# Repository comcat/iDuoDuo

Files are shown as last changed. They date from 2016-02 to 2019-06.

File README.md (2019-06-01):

iDuoDuo - Pet APRS Tracker
=======================================

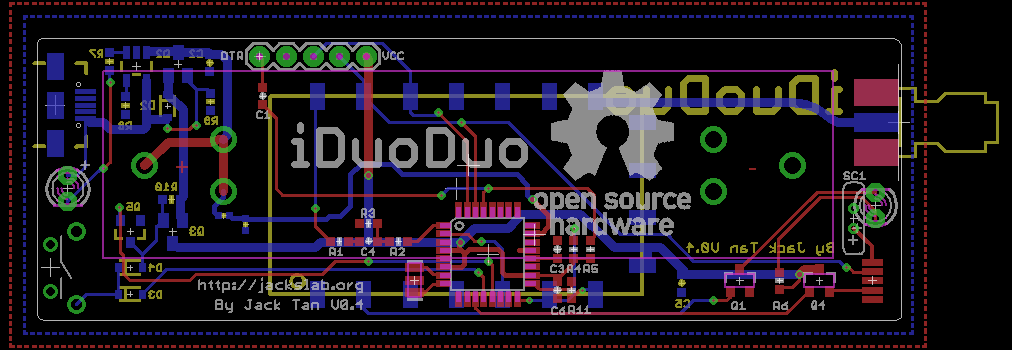
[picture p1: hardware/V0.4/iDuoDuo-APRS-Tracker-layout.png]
iDuoDuo Board V0.4


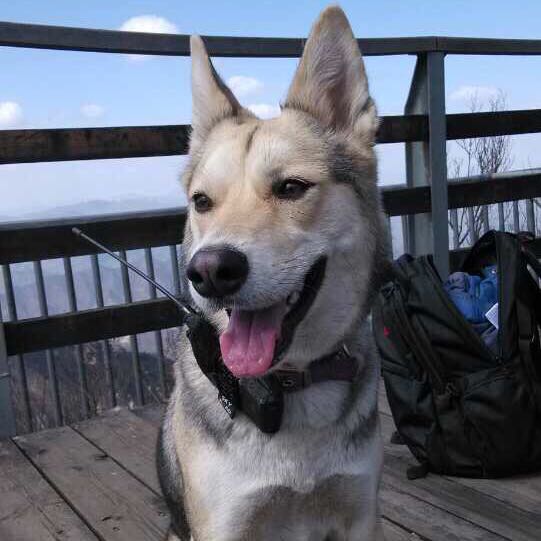
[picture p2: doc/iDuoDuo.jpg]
My DuoDuo


More photo of My DuoDuo :) [My DuoDuo Life](http://comcat.lofter.com/tag/%E5%A4%9A%E5%A4%9A)

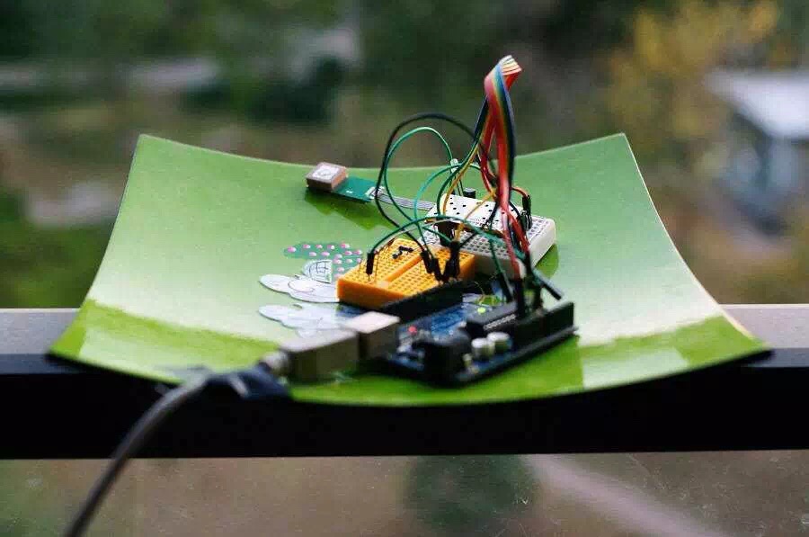
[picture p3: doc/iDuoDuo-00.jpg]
iDuoDuo prototype


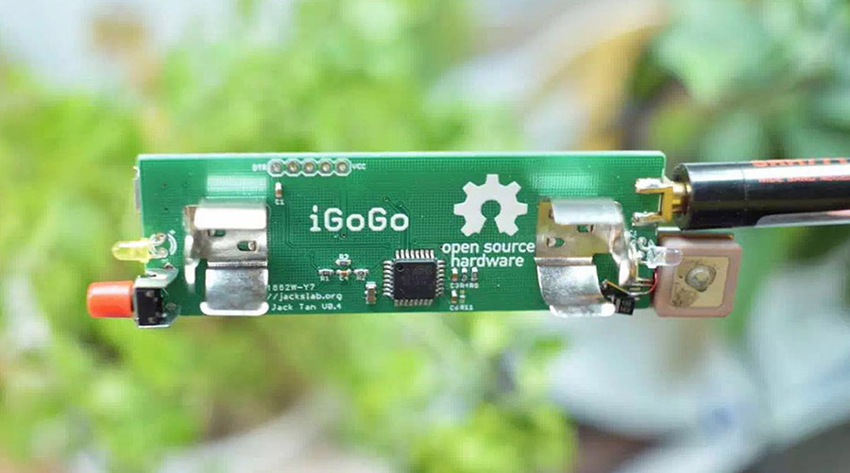
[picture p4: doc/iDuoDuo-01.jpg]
iDuoDuo V0.4


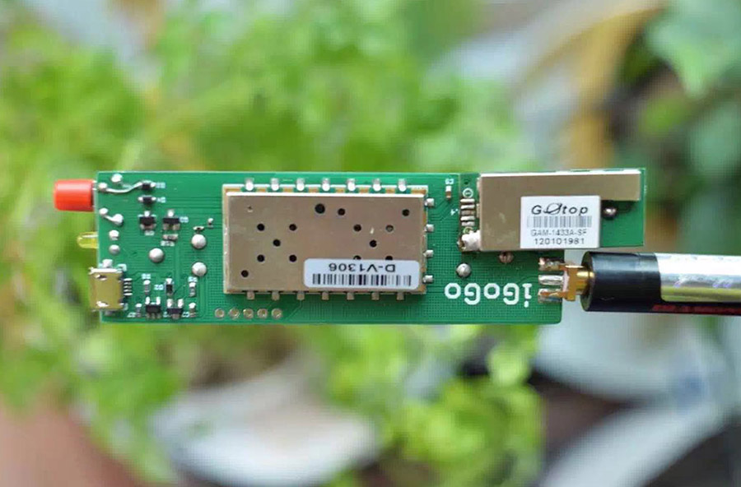
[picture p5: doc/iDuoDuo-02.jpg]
iDuoDuo V0.4


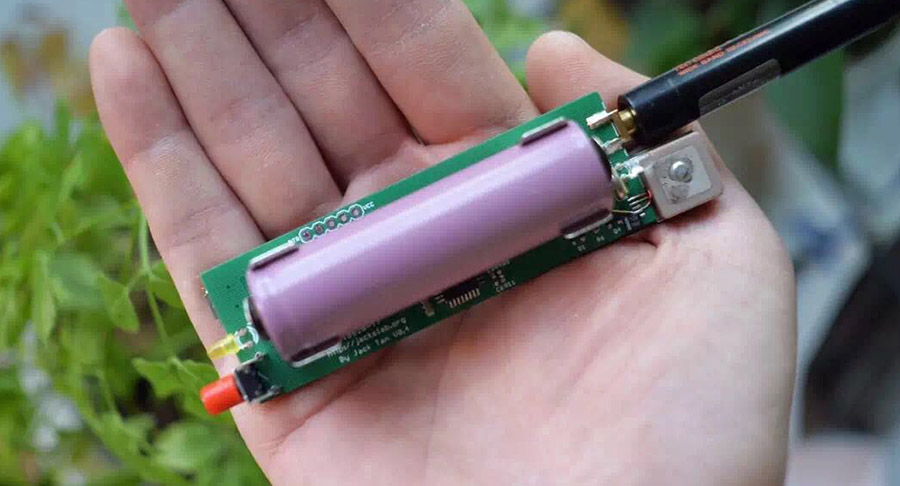
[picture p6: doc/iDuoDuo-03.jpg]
iDuoDuo V0.4


[*iDuoDuo Board*](http://jackslab.org/)

Features
-------------------
* ATMEGA328p MCU, Arduino compatible
* 1W VHF radio module, low cost, about $5 ([SR_FRS_1WV](https://item.taobao.com/item.htm?id=21278567784))
* 1200 bauds AFSK using 8-bit PWM
* Sends out standard APRS position messages
* mini GPS module
* 18650 power supply
* Open Source hardware and firmware 

Pin map
-------------------
iDuoDuo board

* D3 is the audio out pin
* D4 is the PTT pin
* D12 is the PD pin of radio module
* D13 is the PWR_CTRL pin of the radio module

* D8 is the power on input pin
* D9 is the power on output pin

Repository Contents
-------------------
* hardware/ - All Eagle design files (.brd, .sch) and Gerber files of iDuoDuo Board 
* firmware/ - Firmware source files of the iDuoDuo

Product Versions
----------------
* [IDuoDuo-V0.4](hardware/V0.4/) - Stupid bug of the S1 key package. 2016/02/09
* [IDuoDuo-V0.6](hardware/V0.6/) - work OK.

License Information
-------------------
The hardware is released under [Creative Commons ShareAlike 4.0 International](https://creativecommons.org/licenses/by-sa/4.0/).

Distributed as-is; no warranty is given.

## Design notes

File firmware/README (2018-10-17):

How to compile the firmware:
---------------------------------

1. Launch the Arduino IDE(arduino-0022) and open up the firmware.pde

2. Locate the "config.h" tab and replace settings with your own (YOUR CALLSIGN
   GOES THERE).

3. When uploading the firmware, unplug the GPS or flashing will fail with an
error.

http://github.com/trackuino

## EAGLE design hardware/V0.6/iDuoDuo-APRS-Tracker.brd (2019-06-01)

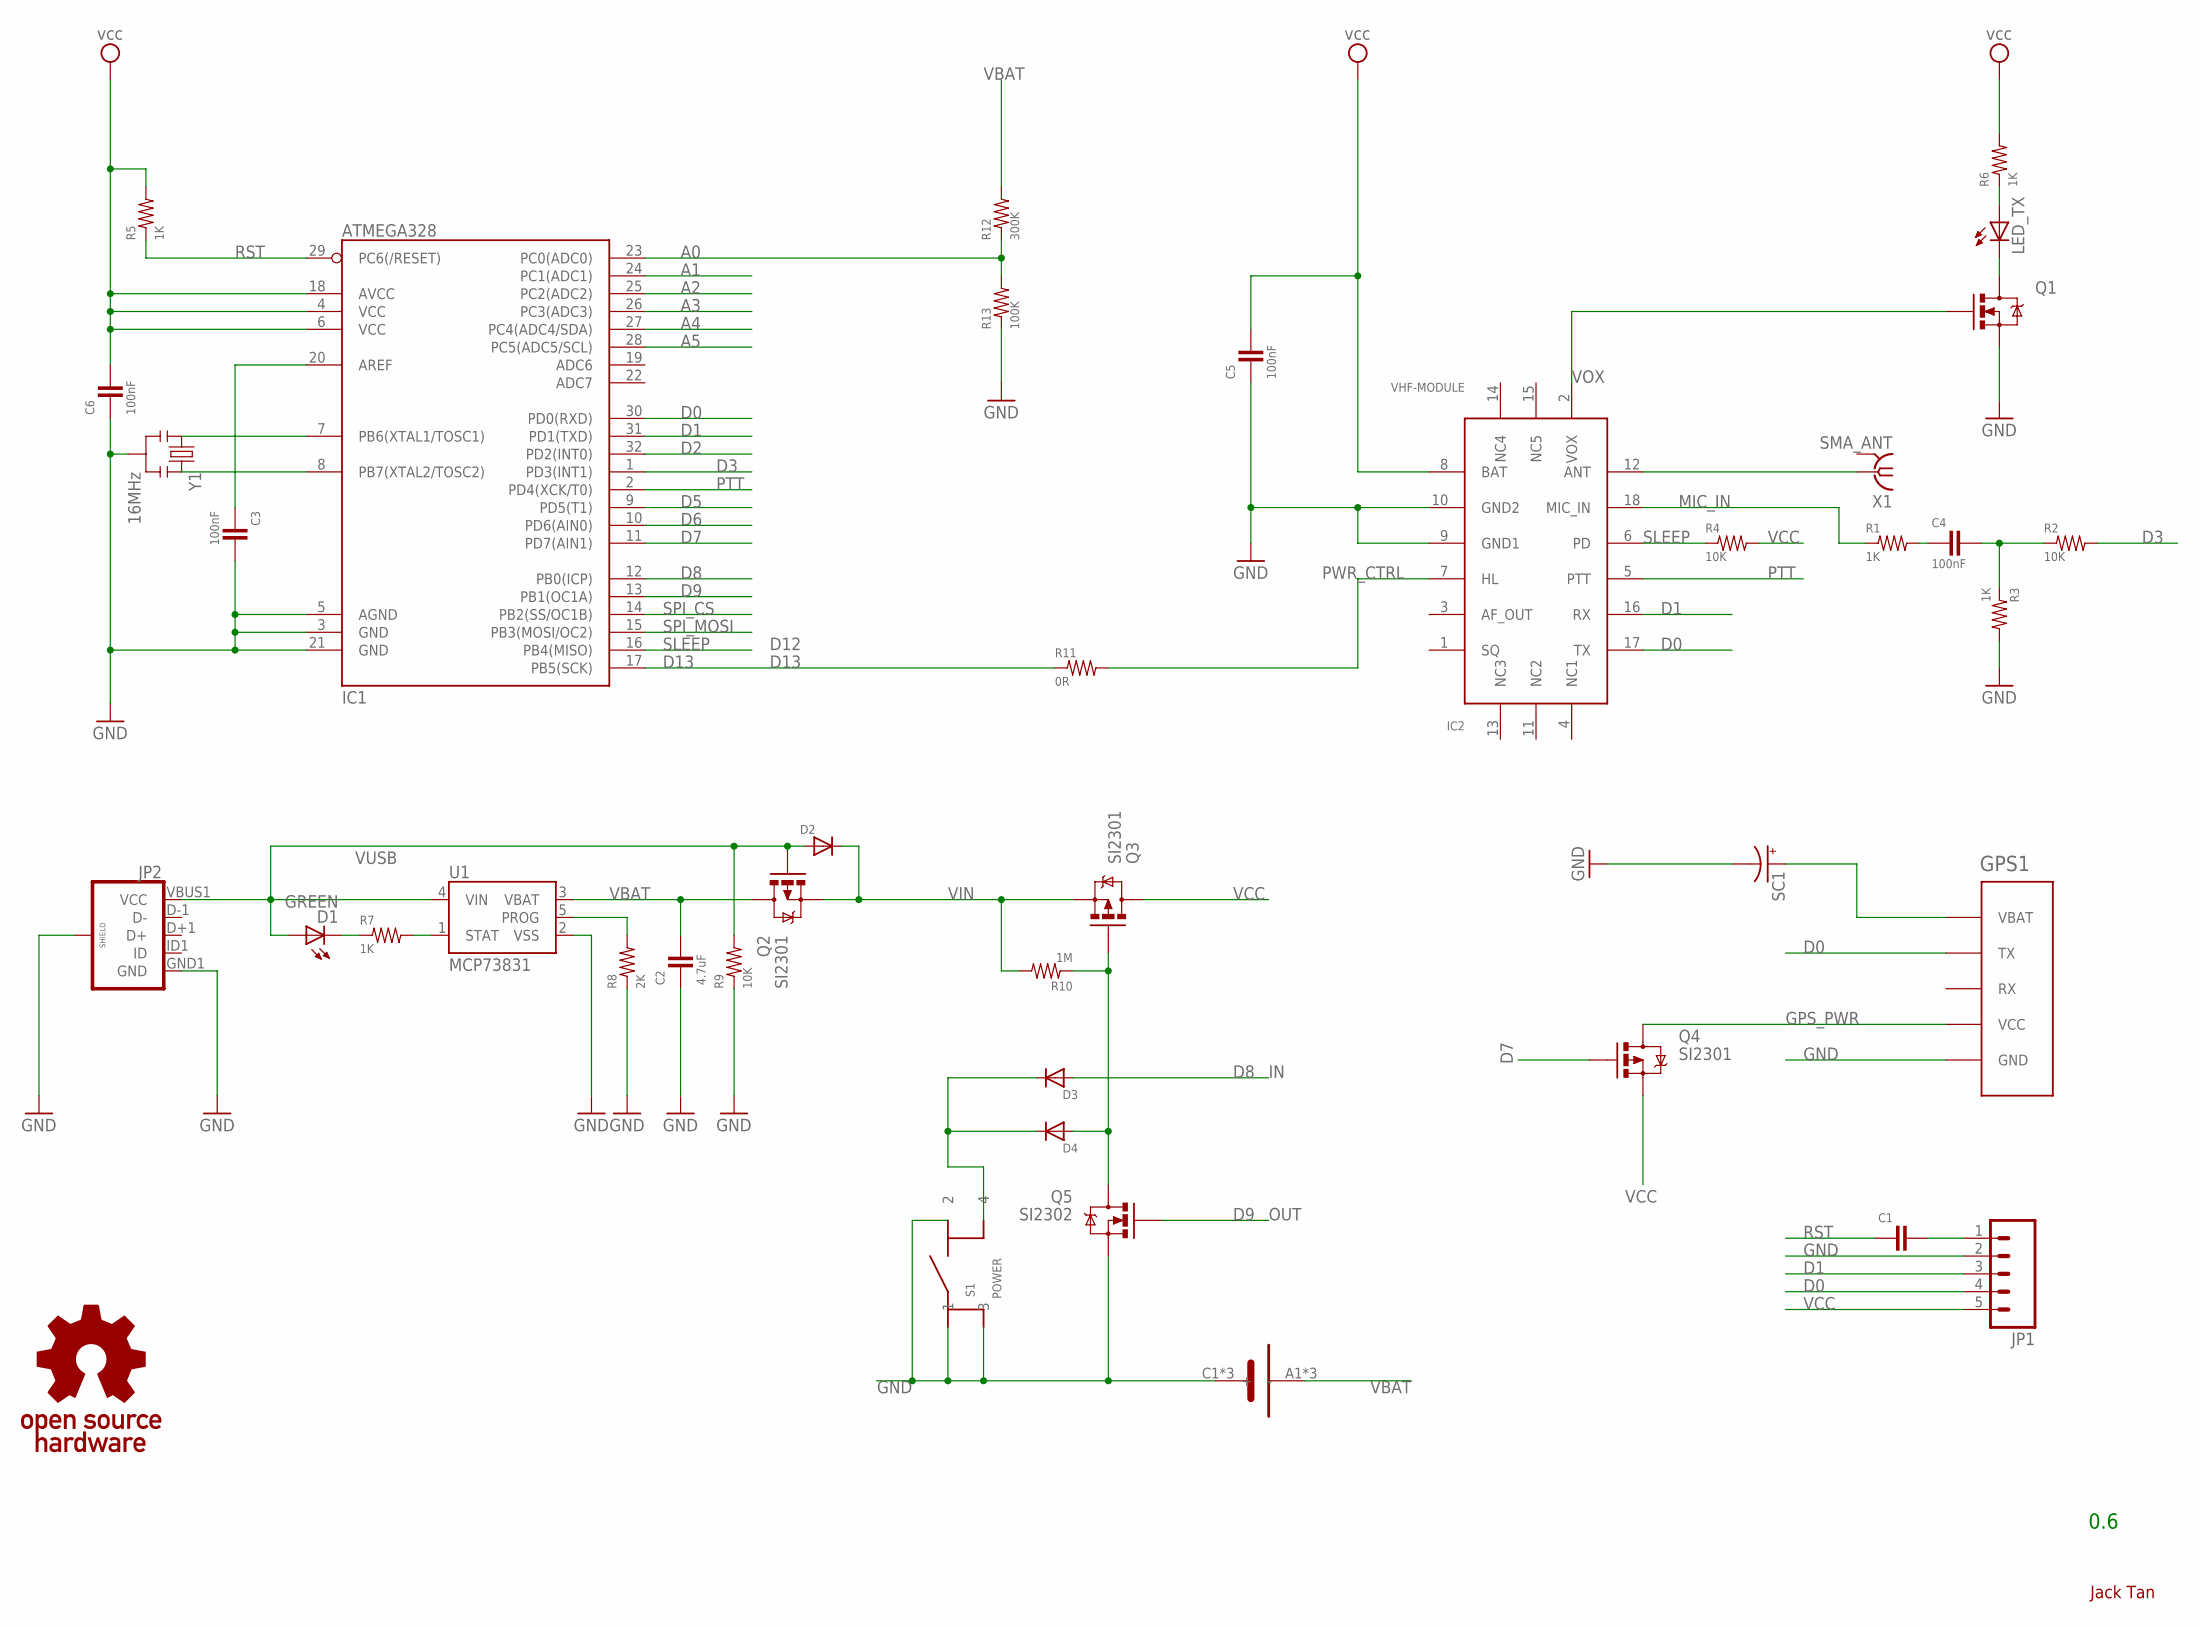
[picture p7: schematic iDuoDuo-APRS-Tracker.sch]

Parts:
B1: 18650
C1: 0603-CAP
C2: 4.7uF; 0603-CAP
C3, C4, C5, C6: 100nF; 0603-CAP
D1: GREEN; LED3MM
D2, D3, D4: DIODESOD; SOD-323
GPS1: GAM-1433
IC1: ATMEGA328; TQFP32-08
IC2: VHF-MODULE
JP1: M05PTH; 1X05
JP2: USB_MICROB_PLUGCONN-11752; USB-B-MICRO-SMD_V03
LED_TX: LED3MM
Q1: MOSFET-N-SMD; SOT23-3
Q2, Q3, Q4: SI2301; SOT23
Q5: SI2302; SOT23-3
R1, R3, R5, R6, R7: 1K; 0603-RES
R2, R4, R9: 10K; 0603-RES
R8: 2K; 0603-RES
R10: 1M; 0603-RES
R11: 0R; 0603-RES
R12: 300K; 0402-RES
R13: 100K; 0402-RES
S1: POWER; SWITCH-TS-038
SC1: SC-3.3-0.22F
U1: MCP73831; SOT23-5
U$1: OPEN_HARDWARE_LOGO
X1: SMA_ANT; SMA-KE
Y1: 16MHz; RESONATOR-SMD

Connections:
A0: IC1.23 (PC0(ADC0)), R12.1, R13.2
A1: IC1.24 (PC1(ADC1))
A2: IC1.25 (PC2(ADC2))
A3: IC1.26 (PC3(ADC3))
A4: IC1.27 (PC4(ADC4/SDA))
A5: IC1.28 (PC5(ADC5/SCL))
D0: GPS1.P$2 (TX), IC1.30 (PD0(RXD)), IC2.17 (TX), JP1.4
D1: IC1.31 (PD1(TXD)), IC2.16 (RX), JP1.3
D2: IC1.32 (PD2(INT0))
D3: IC1.1 (PD3(INT1)), R2.2
D5: IC1.9 (PD5(T1))
D6: IC1.10 (PD6(AIN0))
D7: IC1.11 (PD7(AIN1)), Q4.1 (G)
D8: D3.2 (A), IC1.12 (PB0(ICP))
D9: IC1.13 (PB1(OC1A)), Q5.1 (G)
D13: IC1.17 (PB5(SCK)), R11.1
GND: B1.C1 (-), B1.C2 (-), B1.C3 (-), C2.1, C3.2, C5.1, C6.1, GPS1.P$5 (GND), IC1.3 (GND), IC1.5 (AGND), IC1.21 (GND), IC2.9 (GND1), IC2.10 (GND2), JP1.2, JP2.GND1 (GND), JP2.SHIELD1 (SHIELD), JP2.SHIELD2 (SHIELD), JP2.SHIELD3 (SHIELD), Q1.2 (S), Q5.2 (S), R3.2, R8.1, R9.1, R13.1, S1.1, S1.2, S1.3, SC1.2 (-), U1.2 (VSS), X1.G@1 (GND), X1.G@2 (GND), X1.G@3 (GND), X1.G@4 (GND), Y1.2
GPS_PWR: GPS1.P$4 (VCC), Q4.3 (D)
MIC_IN: IC2.18 (MIC_IN), R1.1
unnamed: IC1.7 (PB6(XTAL1/TOSC1)), Y1.1
unnamed: IC1.8 (PB7(XTAL2/TOSC2)), Y1.3
unnamed: IC2.12 (ANT), X1.1
unnamed: C4.1, R1.2
unnamed: C4.2, R2.1, R3.1
unnamed: C3.1, IC1.20 (AREF)
unnamed: D4.2 (A), Q3.1 (G), Q5.3 (D), R10.1
unnamed: LED_TX.K (C), Q1.3 (D)
unnamed: LED_TX.A, R6.1
unnamed: GPS1.P$1 (VBAT), SC1.1 (+)
unnamed: C1.2, JP1.1
unnamed: D1.K (C), R7.1
unnamed: R7.2, U1.1 (STAT)
unnamed: R8.2, U1.5 (PROG)
unnamed: D3.1 (C), D4.1 (C), S1.4
PTT: IC1.2 (PD4(XCK/T0)), IC2.5 (PTT)
PWR_CTRL: IC2.7 (HL), R11.2
RST: C1.1, IC1.29 (PC6(/RESET)), R5.1
SLEEP: IC1.16 (PB4(MISO)), IC2.6 (PD), R4.1
SPI_CS: IC1.14 (PB2(SS/OC1B))
SPI_MOSI: IC1.15 (PB3(MOSI/OC2))
VBAT: B1.A1 (+), B1.A2 (+), B1.A3 (+), C2.2, Q2.3 (D), R12.2, U1.3 (VBAT)
VCC: C5.2, C6.2, IC1.4 (VCC), IC1.6 (VCC), IC1.18 (AVCC), IC2.8 (BAT), JP1.5, Q3.3 (D), Q4.2 (S), R4.2, R5.2, R6.2
VIN: D2.1 (C), Q2.2 (S), Q3.2 (S), R10.2
VOX: IC2.2 (VOX), Q1.1 (G)
VUSB: D1.A, D2.2 (A), JP2.VBUS1 (VCC), Q2.1 (G), R9.2, U1.4 (VIN)

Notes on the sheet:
0.6
Jack Tan
OUT
D12
D13

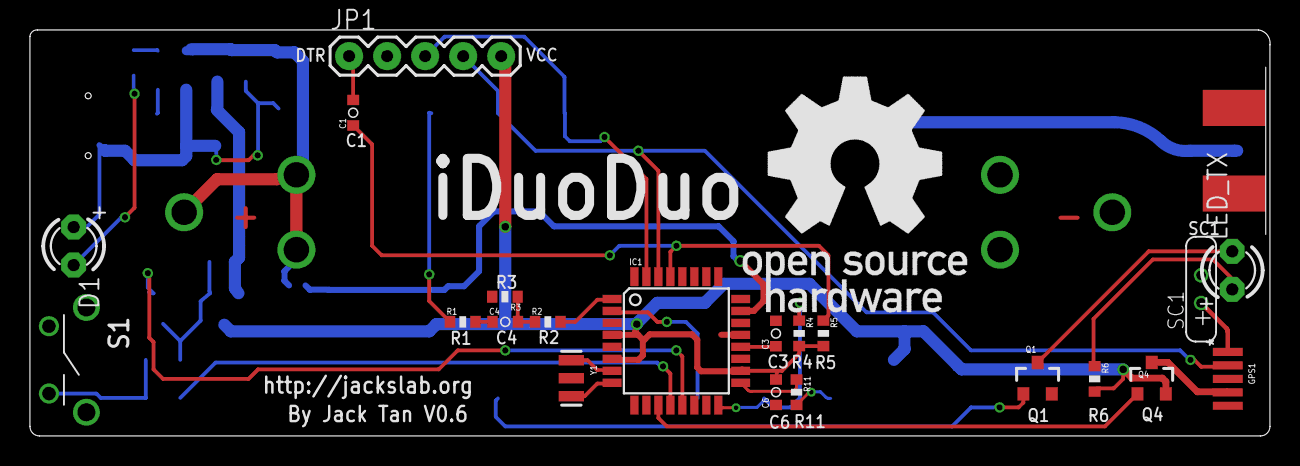
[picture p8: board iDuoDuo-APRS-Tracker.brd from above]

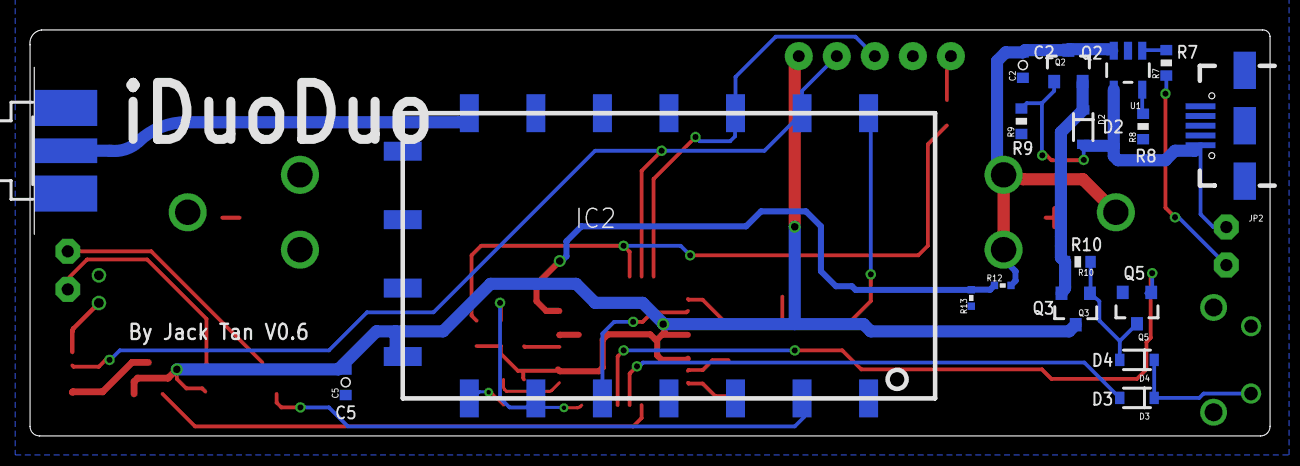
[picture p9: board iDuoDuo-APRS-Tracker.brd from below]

Board: 2 copper layers, 82.8 x 27.1 mm, 41 parts (18 on the bottom side), 35 nets.

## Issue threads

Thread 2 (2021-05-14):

Bill of Materials

DanielSchetritt, 2021-05-14:
Hello!

This is a great project! I want to build one myself. Where can I find the Bill of Materials (BOM)?

Thanks,
Daniel

comcat, 2021-05-17:
You can use the Eagle (v6.6.0 or up) to open the sch file (located at hardware/v0.6), and execute the File->Export -> BOM ...

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

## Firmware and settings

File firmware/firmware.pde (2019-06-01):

/* trackuino copyright (C) 2010  EA5HAV Javi
 *
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
 * You should have received a copy of the GNU General Public License
 * along with this program; if not, write to the Free Software
 * Foundation, Inc., 51 Franklin Street, Fifth Floor, Boston, MA  02110-1301, USA.
 */

// Mpide 22 fails to compile Arduino code because it stupidly defines ARDUINO 
// as an empty macro (hence the +0 hack). UNO32 builds are fine. Just use the
// real Arduino IDE for Arduino builds. Optionally complain to the Mpide
// authors to fix the broken macro.
#if (ARDUINO + 0) == 0
#error "Oops! We need the real Arduino IDE (version 22 or 23) for Arduino builds."
#error "See trackuino.pde for details on this"

// Refuse to compile on arduino version 21 or lower. 22 includes an 
// optimization of the USART code that is critical for real-time operation
// of the AVR code.
#elif (ARDUINO + 0) < 22
#error "Oops! We need Arduino 22 or 23"
#error "See trackuino.pde for details on this"

// Arduino 1.0+ introduced backwards-incompatible changes in the serial lib.
#elif (ARDUINO + 1) >= 100
#error "Ooops! We don't support Arduino 1.0+ (yet). Please use 22 or 23"
#error "See trackuino.pde for details on this"

#endif


// Trackuino custom libs
#include "config.h"
#include "afsk_avr.h"
#include "aprs.h"
#include "buzzer.h"
#include "gps.h"
#include "pin.h"
#include "power.h"
#include "sensors_avr.h"

// Arduino/AVR libs
#include <Wire.h>
#include <WProgram.h>

// Module constants
static const uint32_t VALID_POS_TIMEOUT = 2000;  // ms

// Module variables
static int32_t next_aprs = 0;

void power_on()
{
	pin_write(9, HIGH);
}

void gps_power_on()
{
  pin_write(7, HIGH);
  delay(100);
}

void gps_power_off()
{
  pin_write(7, LOW);
}

void setup()
{
  pinMode(7, OUTPUT);
  pinMode(8, INPUT);
  pinMode(9, OUTPUT);

  if(digitalRead(8) == 0) {
  	power_on();
  }

  Serial.begin(GPS_BAUDRATE);
#ifdef DEBUG_RESET
  Serial.println("RESET");
#endif

  buzzer_setup();
  afsk_setup();

  gps_setup();

  //sensors_setup();

#ifdef DEBUG_SENS
  Serial.print("Ti=");
  Serial.print(sensors_int_lm60());
  Serial.print(", Te=");
  Serial.print(sensors_ext_lm60());
  Serial.print(", Vin=");
  Serial.println(sensors_vin());
#endif
  
  // Do not start until we get a valid time reference
  // for slotted transmissions.
  if (APRS_SLOT >= 0) {

#ifndef DISABLE_GPS
    gps_power_on();
    
    do {
      while (! Serial.available())
        power_save();
    } while (! gps_decode(Serial.read()));

    gps_power_off();
    
    next_aprs = millis() + 1000 *
      (APRS_PERIOD - (gps_seconds + APRS_PERIOD - APRS_SLOT) % APRS_PERIOD);
#endif
  }
  else {
    next_aprs = millis();
  }  
  // TODO: beep while we get a fix, maybe indicating the number of
  // visible satellites by a series of short beeps?
}

void get_pos()
{
  // Get a valid position from the GPS
  int valid_pos = 0;

  gps_power_on();

  uint32_t timeout = millis();
  do {
    if (Serial.available())
      valid_pos = gps_decode(Serial.read());
  } while ( (millis() - timeout < VALID_POS_TIMEOUT) && ! valid_pos) ;

  if (valid_pos) {
    if (gps_altitude > BUZZER_ALTITUDE) {
      buzzer_off();   // In space, no one can hear you buzz
    } else {
      buzzer_on();
    }
  }

  gps_power_off();
}

void loop()
{
  // Time for another APRS frame
  if ((int32_t) (millis() - next_aprs) >= 0) {
#ifndef DISABLE_GPS
    get_pos();
#endif
    aprs_send();
    next_aprs += APRS_PERIOD * 1000L;
    //while (afsk_busy()) ;
      //power_save();

#ifdef DEBUG_MODEM
    // Show modem ISR stats from the previous transmission
    afsk_debug();
#endif
  }

  power_save(); // Incoming GPS data or interrupts will wake us up
}

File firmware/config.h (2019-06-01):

/* trackuino copyright (C) 2010  EA5HAV Javi
 *
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
 * You should have received a copy of the GNU General Public License
 * along with this program; if not, write to the Free Software
 * Foundation, Inc., 51 Franklin Street, Fifth Floor, Boston, MA  02110-1301, USA.
 */

#ifndef __CONFIG_H__
#define __CONFIG_H__

#define	DISABLE_GPS		1

// --------------------------------------------------------------------------
// THIS IS THE TRACKUINO FIRMWARE CONFIGURATION FILE. YOUR CALLSIGN AND
// OTHER SETTINGS GO HERE.
//
// NOTE: all pins are Arduino based, not the Atmega chip. Mapping:
// http://www.arduino.cc/en/Hacking/PinMapping
// --------------------------------------------------------------------------


// --------------------------------------------------------------------------
// APRS config (aprs.c)
// --------------------------------------------------------------------------

// Set your callsign and SSID here. Common values for the SSID are
// (from http://zlhams.wikidot.com/aprs-ssidguide):
//
// - Balloons:  11
// - Cars:       9
// - Home:       0
// - IGate:      5
#define S_CALLSIGN		"DUODUO"
#define S_CALLSIGN_ID	9

// Destination callsign: APRS (with SSID=0) is usually okay.
#define D_CALLSIGN      "APRS"
#define D_CALLSIGN_ID   0

// Digipeating paths:
// (read more about digipeating paths here: http://wa8lmf.net/DigiPaths/ )
// The recommended digi path for a balloon is WIDE2-1 or pathless. The default
// is pathless. Uncomment the following two lines for WIDE2-1 path:
#define DIGI_PATH1      "WIDE2"
#define DIGI_PATH1_TTL  1

// APRS comment: this goes in the comment portion of the APRS message. You
// might want to keep this short. The longer the packet, the more vulnerable
// it is to noise. 
#define APRS_COMMENT    ">EPRS="


// --------------------------------------------------------------------------
// AX.25 config (ax25.cpp)
// --------------------------------------------------------------------------

// TX delay in milliseconds
#define TX_DELAY      300

// --------------------------------------------------------------------------
// Tracker config (trackuino.pde)
// --------------------------------------------------------------------------

// APRS packets are slotted so that multiple trackers can be used without
// them stepping on one another. The transmission times are governed by
// the formula:
//
//         APRS_SLOT (seconds) + n * APRS_PERIOD (seconds)
//
// When launching multiple balloons, use the same APRS_PERIOD in all balloons
// and set APRS_SLOT so that the packets are spaced equally in time.
// Eg. for two balloons and APRS_PERIOD = 60, set APRS_SLOT to 0 and 30, 
// respectively. The first balloon will transmit at 00:00:00, 00:01:00, 
// 00:02:00, etc. amd the second balloon will transmit at 00:00:30, 00:01:30,
// 00:02:30, etc.
#define APRS_SLOT     0     // seconds. -1 disables slotted transmissions
#define APRS_PERIOD   15    // seconds

// GPS baud rate (in bits per second). This is also the baud rate at which
// debug data will be printed out the serial port.
#define GPS_BAUDRATE  9600


// --------------------------------------------------------------------------
// Modem config (afsk.cpp)
// --------------------------------------------------------------------------

// AUDIO_PIN is the audio-out pin. The audio is generated by timer 2 using
// PWM, so the only two options are pins 3 and 11.
// Pin 11 doubles as MOSI, so I suggest using pin 3 for PWM and leave 11 free
// in case you ever want to interface with an SPI device.
#define AUDIO_PIN       3

// --------------------------------------------------------------------------
// Radio config (radio_dmo.cpp)
// --------------------------------------------------------------------------

// This is the PTT (RF TX) and PD (sleep ctrl) pin
#define PTT_PIN         4
#define PD_PIN			12

// use the TX PIN to send the AT cmd to Radio module
#define RF_RX_PIN		1		

// --------------------------------------------------------------------------
// Sensors config (sensors.cpp)
// --------------------------------------------------------------------------

// Most of the sensors.cpp functions use internal reference voltages (either
// AVCC or 1.1V). If you want to use an external reference, you should
// uncomment the following line:
//
// #define USE_AREF
//
// BEWARE! If you hook up an external voltage to the AREF pin and 
// accidentally set the ADC to any of the internal references, YOU WILL
// FRY YOUR AVR.
//
// It is always advised to connect the AREF pin through a pull-up resistor,
// whose value is defined here in ohms (set to 0 if no pull-up):
//
#define AREF_PULLUP           4700
//
// Since there is already a 32K resistor at the ADC pin, the actual
// voltage read will be VREF * 32 / (32 + AREF_PULLUP)
//
// Read more in the Arduino reference docs:
// http://arduino.cc/en/Reference/AnalogReference?from=Reference.AREF
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

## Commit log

2016-02-09 hardware: add Eagle design files (*.sch and *.brd) of v0.4
    [iGoGo-APRS-Tracker.brd, iGoGo-APRS-Tracker.sch]
2016-02-09 hardware: add the gerber files of v0.4
2018-10-17 Try to add the method function set_freq of Radio module
    Now we use the PIN 1 (UART TX) as the transmit pin to send
    the AT CMDs to the Radio Module.
2018-10-17 disable the led pin
2018-10-17 suppot iGoGo board
    * D3 is the audio out pin
    * D4 is the PTT pin
    * D12 is the PD pin of radio module
    * D13 is the PWR_CTRL pin of the radio module
    * D8 is the power on input pin
    * D9 is the power on output pin
2018-10-17 try to add the power on support
2019-06-01 hardware: remove the gerber files of v0.4
    There a stupid error about the package of the key...
2019-06-01 rename the iGoGo to iDuoDuo
    [iDuoDuo-APRS-Tracker.brd, iDuoDuo-APRS-Tracker.sch]
2019-06-01 hardware: remove the gerber files directory
2019-06-01 hardware: add a new version v0.6
    fixed the stupid bug of S1 key package
    [iDuoDuo-APRS-Tracker.brd, iDuoDuo-APRS-Tracker.sch]
2019-06-01 hardware: fix the gps switch bug of v0.6
    [iDuoDuo-APRS-Tracker.brd, iDuoDuo-APRS-Tracker.sch]
2019-06-01 firmware: add a macro switch to disable the gps for testing
2019-06-01 firmware: add the cores and libs of arduino-0022
    add a makefile to support compiling from cmdline
2019-06-01 firmware: try to fix the build error when use the new toolchain
    [afsk_avr.cpp]
2019-06-01 firmware: support the old toolchain (arduino-0022)
2019-06-01 firmware: using the arduino-0022 build system by default

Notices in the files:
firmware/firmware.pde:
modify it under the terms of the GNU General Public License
